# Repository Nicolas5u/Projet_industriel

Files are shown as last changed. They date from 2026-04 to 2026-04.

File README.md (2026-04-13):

# English readme below the French readme
# Projet industriel
Ce projet est un projet étudiant en lien avec l'entreprise Sony CSL

# Montage outil Seringue

L’outil Seringue a pour objectif de rendre la jubilee capable d'utiliser une seringue automatiquement, rendant notamment capable d'obtenir une quantité constante d’eau dans les puits d’une plaque multi-puits (2.5 +- 0.3 ml). Les problématiques de contamination des liquides ne sont pas prises en compte dans cette solution.

D’un point de vue mécanique nous avons une pièce support qui permet de fixer le moteur à courant continu permettant un effort vertical sur la seringue. La deuxième pièce fixée à la première permet de fixer la partie extérieure de la seringue au support et de fixer le capteur de liquide.

Electronique : nous avons utilisé une raspberry pi connectée à un driver mjkdz pour alimenter et contrôler le moteur à courant continu. Le capteur de liquide est directement connecté à une arduino (utilisé en tant que convertisseur analogique numérique).
Le MJDKZ motor driver module sert principalement à contrôler facilement la vitesse (permet d’augmenter ou diminuer la vitesse du moteur, d’avoir un contrôle souple et précis) et le sens d’un moteur DC (pont en h) à partir d’un microcontrôleur, tout en lui fournissant l’alimentation appropriée (externe à la carte arduino) et en le protégeant (des surtensions, pics de courant, parasites électriques).
Le capteur de niveau de liquide sert principalement à détecter la présence et mesurer la profondeur d'un fluide (jusqu'à 48 mm) à partir d'un microcontrôleur disposant d'une entrée analogique, tout en offrant une lecture continue (grâce à un circuit d'amplification par transistor générant une tension proportionnelle à l'immersion) utilisable pour concevoir facilement des systèmes d'alarme ou de surveillance de niveau.

Il est nécessaire d’acheter le moteur :  
https://www.amazon.fr/Actuator-electronic-controller-EKFBQBGW-5V-50mm-15N/dp/B0D9RP563V?th=1&psc=1  

Il est nécessaire d’acheter un driver :  
https://fr.aliexpress.com/item/1005008699170894.html  

Il est nécessaire d’acheter un convertisseur analogique numérique (en remplacement de la carte arduino) :  
https://fr.aliexpress.com/item/1005007112138921.html  

Il est nécessaire d’imprimer :  
1 : Piece_support_outil_seringue.stl  
2 : Piece_capteur_outil_seringue.stl  
3 : Piece_maintien_seringue.stl  
4 : Piece_moteur_outil_seringue.stl  

Les pièces sont également visibles sur Printables :
https://www.printables.com/model/1675196-piece_support_outil_seringue



# Test sur la seringue

L’objectif est ici de mesurer la différence de quantité d'eau déversée par l'outil seringue. Pour ce faire nous avons positionné la seringue à une hauteur qui restera constante durant toute la durée de l'expérience. Il nous a alors suffit d’utiliser la fonction remplissage de puits qui actionne le moteur jusqu’à ce que le sensor envoie une valeur supérieure à celle prédéfinie.  


Il est important de noter que certains biais ont été remarqués comme une goutte d’eau qui serait restée au niveau de la seringue.  




# Code
Première utilisation de l’outil seringue 

-> allumer raspi + machine Jubilee  
-> connection au wifi : CSLToi  
-> dans la barre de recherche d’un navigateur : http://jubilee.local/ ou  http://10.0.9.6/  
-> Faire le homing pour vérifier que tout va bien (touche du tableau de bord “ Tout au Origines”)  

Cloner le repo https://github.com/leosabatie-eng/science-jubilee.git    
 
Installer conda (plus propre avec le lien qu’avec une commande du terminal) :  
https://docs.conda.io/projects/conda/en/stable/user-guide/install/windows.html  

-> se positionner dans le fichier science_jubilee  
-> conda create -n jubilee26 python=3.9  
-> conda activate jubilee26  

-> conda install conda-forge::jupyterlab  
-> jupyter lab  

Utilisation de l’outil seringue

Une fois les étapes de première connexion réalisées, l’utilisation de l’outil seringue se fait par la compilation du serveur qui envoie les données du capteur et reçoit l’instruction pour le moteur qui actionne la seringue.  

Dans un terminal:  
-> ssh jubilee@[adresse IP]
il est demandé le mot de passe : [mdp]  
-> python serveur_pi.py

Dans un terminal (au niveau de science jubilee):  
-> conda activate jubilee26  
-> jupyter lab  

Aller sur l’interface sur internet  
Se déplacer dans le répertoire science-jubilee/src/science_jubilee/a_netbookTest/test_ser.ipynb  

Modification d’un fichier de l’espace mémoire de la raspberry  

Dans le cas de modification du fichier il est conseillé d’utiliser vscode avec son extension   
remote - ssh la commande et le mots de passe pour se connecter reste identique. Il est alors facile d’ouvrir le dossier home/jubilee qui contient tous les codes qui sont dans l’espace mémoire de la raspberry et de les modifier.  

Utilisation du code test_ser.ipynb  

Seules deux fonctions sont réellement nécessaires pour la manipulation de l’outil seringue  
-> tool1.remplir_seringue(temps_secondes=10.0)  
-> tool1.avancer_jusqu_au_seuil(seuil=1, timeout_sec=5)  
la première permet de remplir la seringue pendant le temps indiqué en paramètre (il y est fixé un temps de 4 secondes de vidage de la seringue au début de la fonction)  
la seconde permet de vider la seringue jusqu’à un certain niveau de seuil (valeur en volt facilement réglable avec le fichier “moniteur_capteur.py” il faut bien sur avoir lancé le serveur et être sur le wifi CSL toi)  

Erreur dans l’utilisation du code test_ser.ipynb  

En cas de difficulté dans les liens (les imports sont introuvables) faire : pip install -e dans un terminal au niveau de science jubilee  

# Industrial_project
This project is a student project in collaboration with the company Sony CSL

# Syringe tool assembly

The Syringe tool aims to make the Jubilee capable of using a syringe automatically, notably enabling it to obtain a constant amount of water in the wells of a multi-well plate. Liquid contamination issues are not taken into account in this solution.

From a mechanical point of view, we have a support part that allows the motor to be mounted, providing vertical force on the syringe. The second part, attached to the first one, allows the outer part of the syringe to be fixed to the support and to mount the liquid sensor.

Electronics: we used a Raspberry Pi connected to an mjkdz driver to power and control the motor. The liquid sensor is directly connected to an Arduino (used as an analog-to-digital converter).
The MJDKZ motor driver module is mainly used to easily control the speed (allows increasing or decreasing the motor speed, providing smooth and precise control) and the direction of a DC motor (H-bridge) from a microcontroller, while providing it with the appropriate power supply (external to the Arduino) and protecting it (from overvoltages, current spikes, and electrical noise).
The liquid level sensor is mainly used to detect the presence and measure the depth of a fluid (up to 48 mm) from a microcontroller with an analog input, while offering continuous reading (thanks to a transistor amplification circuit generating a voltage proportional to the immersion) usable to easily design alarm or level monitoring systems.

It is necessary to buy the motor: 
[https://www.amazon.fr/Actuator-electronic-controller-EKFBQBGW-5V-50mm-15N/dp/B0D9RP563V?th=1&psc=1](https://www.amazon.fr/Actuator-electronic-controller-EKFBQBGW-5V-50mm-15N/dp/B0D9RP563V?th=1&psc=1)

It is necessary to print:  
1 : Piece_support_outil_seringue.stl  
2 : Piece_capteur_outil_seringue.stl  
3 : Piece_maintien_seringue.stl  
4 : Piece_moteur_outil_seringue.stl  

The parts are also visible on Printables:
[https://www.printables.com/model/1675196-piece_support_outil_seringue](https://www.printables.com/model/1675196-piece_support_outil_seringue)



# Syringe test

The objective here is to measure the difference in the amount of water dispensed by the syringe tool. To do this, we positioned the syringe at a height that will remain constant throughout the duration of the experiment. We then simply used the well-filling function, which activates the motor until the sensor sends a value higher than the predefined one.  


It is important to note that some biases were noticed, such as a drop of water that might have stayed on the syringe tip.  




# Code
First use of the syringe tool  

-> turn on raspi + Jubilee machine  
-> connect to wifi: CSLToi  
-> in a browser's search bar: [http://jubilee.local/](http://jubilee.local/) or [http://10.0.9.6/](http://10.0.9.6/)  
-> Home the machine to check that everything is fine (dashboard button "Home All" / "Tout aux origines")  

Clone the repo https://github.com/leosabatie-eng/science-jubilee.git  
 
Install conda (cleaner with the link than with a terminal command):  
[https://docs.conda.io/projects/conda/en/stable/user-guide/install/windows.html](https://docs.conda.io/projects/conda/en/stable/user-guide/install/windows.html)  

-> navigate into the sciencejubilee folder  
-> conda create -n jubilee26 python=3.9  
-> conda activate jubilee26  

-> conda install conda-forge::jupyterlab  
-> jupyter lab

Using the syringe tool  

Once the initial connection steps are completed, the syringe tool is used by running the server which sends the sensor data and receives the instruction for the motor that actuates the syringe.

In a terminal:
-> ssh jubilee@[IP]
the password is requested: [..]  
-> python serveur_pi.py  

In a terminal (at the science jubilee level):  
-> conda activate jubilee26  
-> jupyter lab  

Go to the web interface  
Navigate to the directory science-jubilee/src/science_jubilee/a_netbookTest/test_ser.ipynb  

Modifying a file in the Raspberry Pi's memory space  

If modifying the file, it is recommended to use vscode with its remote - ssh extension. The command and password to connect remain the same. It is then easy to open the home/jubilee folder which contains all the codes that are in the Raspberry Pi's memory space and modify them.  

Using the test_ser.ipynb code  

Only two functions are actually for manipulating the syringe tool  
-> tool1.remplir_seringue(temps_secondes=10.0)  
-> tool1.avancer_jusqu_au_seuil(seuil=1, timeout_sec=5)  
the first one allows filling the syringe for the time indicated in the parameter (a 4-second syringe emptying time is set at the beginning of the function)  
the second one allows emptying the syringe up to a certain threshold level (voltage value easily adjustable with the "python moniteur_capteur.py" file, you must of course have launched the server and be on the CSLToi wifi)  

Error when using the test_ser.ipynb code  

In case of difficulty with the links (imports cannot be found) run: pip install -e in a terminal at the science jubilee level

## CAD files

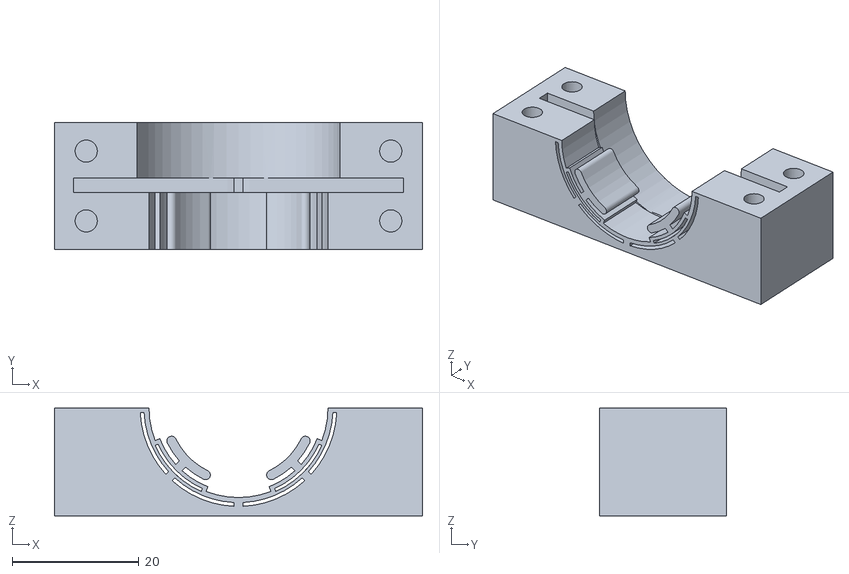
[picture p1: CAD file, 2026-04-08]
Piece_maintien_seringue.STL
58.0 x 20.0 x 17.0

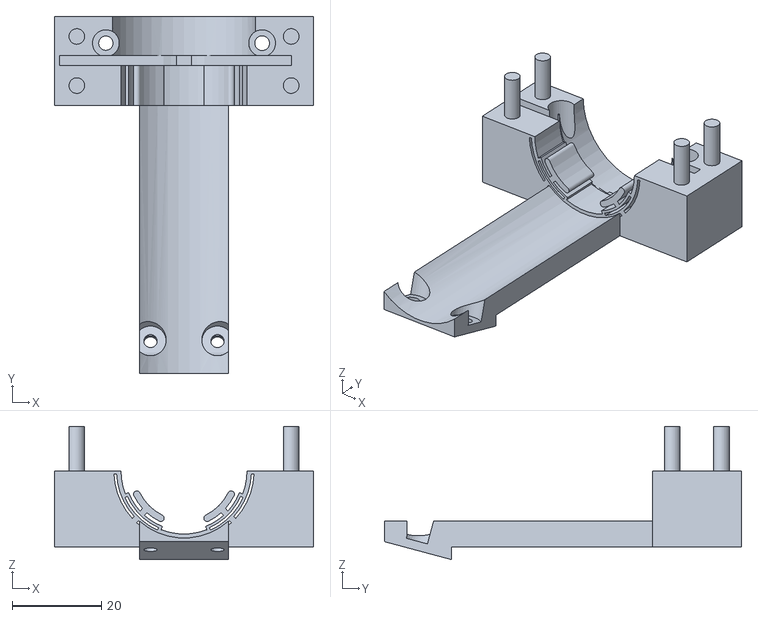
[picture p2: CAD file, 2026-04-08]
Piece_capteur_outil_seringue.STL
58.0 x 80.0 x 29.8

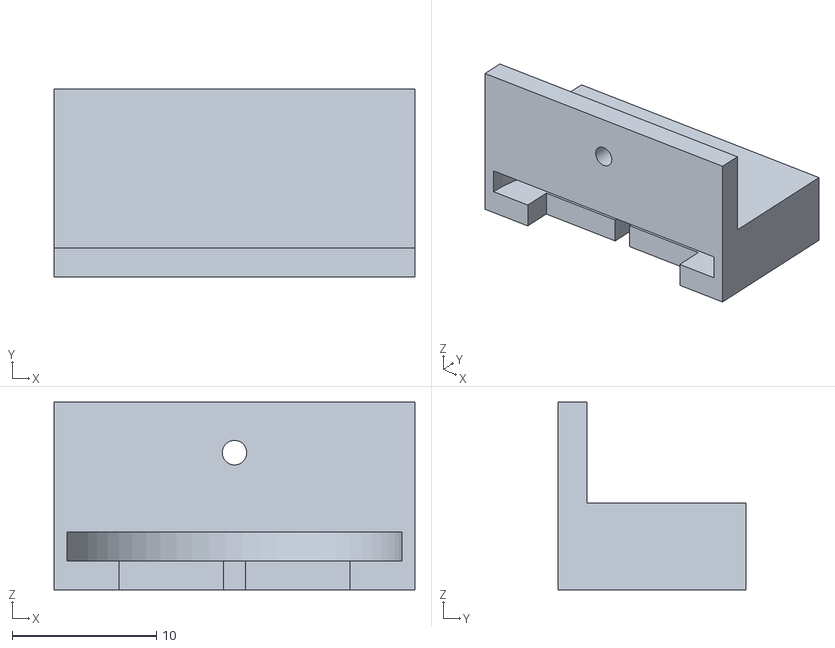
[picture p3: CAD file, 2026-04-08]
Piece_moteur_outil_seringue.STL
25.0 x 13.0 x 13.0

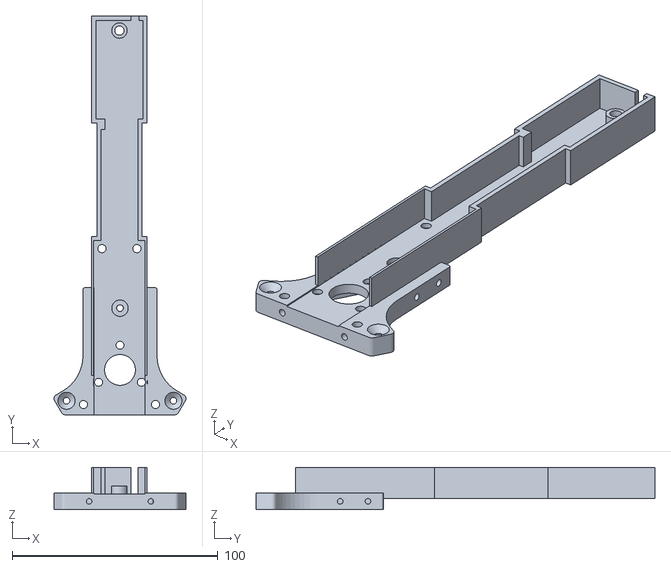
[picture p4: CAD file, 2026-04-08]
Piece_support_outil_seringue.STL
64.2 x 193.8 x 20.5

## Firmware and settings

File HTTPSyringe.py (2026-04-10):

import json
import logging
import os
import time
from itertools import dropwhile, takewhile
from typing import Iterator, List, Tuple, Union

import numpy as np
import requests

from science_jubilee.labware.Labware import Labware, Location, Well
from science_jubilee.tools.Tool import (
    Tool,
    ToolConfigurationError,
    ToolStateError,
    requires_active_tool,
)


class HTTPSyringe(Tool):
    def __init__(self, index, name, url, ip_raspberry="10.0.9.55"):
        """
        HTTP Syringe est un client pur : parle à Jubilee (url) et à notre serveur Pi.
        """
        self.name = name
        self.index = index
        self.url = url
        # ⚠ Port 5001 pour éviter le conflit avec OctoPrint
        self.url_materiel = f"http://{ip_raspberry}:5001"  

        # --- Initialisation HTTP standard de Jubilee ---
        config_r = requests.post(url + "/get_config", json={"name": name})
        config = config_r.json()
        super().__init__(index, **config, url=url)

        # Vérifie le serveur Pi
        self._init_gpio()

        # Status initial
        status_r = requests.post(url + "/get_status", json={"name": name})
        status = status_r.json()
        self.syringe_loaded = status.get("syringe_loaded", False)
        self.remaining_volume = status.get("remaining_volume", 0.0)

    def _init_gpio(self):
        """
        Initialise la connexion réseau avec le serveur matériel du Raspberry Pi.
        
        Cette fonction effectue un "ping" (requête GET) vers le Raspberry Pi pour 
        vérifier s'il est allumé et prêt à recevoir des commandes. Elle met à jour 
        l'attribut `self.gpio_disponible` en conséquence.

        Auteur : Nicolas Durand (Projet étudiant - Sony CSL)
        """
        if getattr(self, "gpio_disponible", False):
            return

        try:
            requests.get(f"{self.url_materiel}/capteur", timeout=2)
            self.gpio_disponible = True
            print(f"[{self.name}] Connecté au serveur matériel du Raspberry Pi.")
        except requests.exceptions.RequestException:
            self.gpio_disponible = False
            print(f"[{self.name}] ERREUR : Impossible de joindre le Pi sur {self.url_materiel}.")

    def lire_capteur(self):
        """
        Interroge le Raspberry Pi pour obtenir la valeur immédiate du capteur de liquide.
        
        Idéal pour le monitoring en direct ou pour tester le capteur sans activer le moteur.

        Returns:
            tuple: (tension en Volts, valeur_brute de 0 à 1023). 
                   Retourne (None, None) en cas d'échec de connexion.

        Auteur : Nicolas Durand (Projet étudiant - Sony CSL)
        """
        self._init_gpio()
        if not getattr(self, "gpio_disponible", False):
            return None, None
            
        try:
            req = requests.get(f"{self.url_materiel}/capteur", timeout=2)
            reponse = req.json()
            tension = reponse.get("tension", 0.0)
            brute = reponse.get("brute", 0)
            return tension, brute
        except Exception:
            return None, None

    @requires_active_tool
    def avancer_jusqu_au_seuil(self, seuil: float = 1.0, timeout_sec: int = 5):
        """
        Descend l'outil vers le réservoir jusqu'à la détection du liquide.
        
        Active le moteur en marche avant et interroge en boucle le capteur via le Pi.
        Dès que la tension lue est supérieure ou égale au seuil, le moteur s'arrête.
        Intègre une sécurité (timeout) pour éviter le crash physique de l'outil si 
        le capteur est défaillant ou le réservoir vide.

        Args:
            seuil (float): La tension cible (en Volts) confirmant la présence de liquide.
            timeout_sec (int): Temps maximum (en secondes) avant l'arrêt d'urgence.

        Raises:
            ToolStateError: Si le serveur Raspberry Pi est injoignable avant le mouvement.

        Auteur : Nicolas Durand (Projet étudiant - Sony CSL)
        """
        self._init_gpio()
        if not getattr(self, "gpio_disponible", False):
            raise ToolStateError("Le serveur Pi n'est pas joignable.")

        print(f"[{self.name}] Ordre au Pi : Moteur forward (Attente seuil >= {seuil}V)")
        requests.post(f"{self.url_materiel}/moteur", json={"action": "forward", "speed": 1.0})
        
        start_time = time.time()
        try:
            while True:
                try:
                    req = requests.get(f"{self.url_materiel}/capteur", timeout=1)
                    tension_actuelle = req.json().get("tension", 0.0)
                except Exception:
                    tension_actuelle = 0.0 

                if tension_actuelle >= seuil:
                    print(f"[{self.name}] Seuil atteint ({tension_actuelle:.2f}V).")
                    break
                    
                if (time.time() - start_time) > timeout_sec:
                    print(f"[{self.name}] Timeout atteint ({timeout_sec}s).")
                    break
                    
                time.sleep(0.1)
                
        finally:
            # Bloc "finally" garantissant l'arrêt du moteur même en cas de crash (Ctrl+C)
            requests.post(f"{self.url_materiel}/moteur", json={"action": "stop"})
            print(f"[{self.name}] Moteur arrêté.")

    @requires_active_tool
    def remplir_seringue(self, temps_secondes: float):
        """
        Exécute une séquence de purge et de remplissage automatisée de la seringue.
        
        1. Marche avant (4s) : Vide l'air ou le liquide résiduel dans le réservoir source.
        2. Marche arrière (variable) : Aspire le nouveau liquide.

        Args:
            temps_secondes (float): Durée d'activation du moteur en marche arrière pour l'aspiration.

        Auteur : Nicolas Durand (Projet étudiant - Sony CSL)
        """
        self._init_gpio()
        if not getattr(self, "gpio_disponible", False):
            raise ToolStateError("Le serveur Pi n'est pas joignable.")

        temps_vide = 4.0
        print(f"[{self.name}] Vidage en cours pour {temps_vide} sec...")
        requests.post(f"{self.url_materiel}/moteur", json={"action": "forward", "speed": 1.0})
        time.sleep(temps_vide)

        print(f"[{self.name}] Remplissage en cours pour {temps_secondes} sec...")
        requests.post(f"{self.url_materiel}/moteur", json={"action": "backward", "speed": 1.0})
        time.sleep(temps_secondes)

        requests.post(f"{self.url_materiel}/moteur", json={"action": "stop"})
        print(f"[{self.name}] Remplissage terminé.")

        if hasattr(self, 'capacity'):
            self.remaining_volume = self.capacity

    def cleanup_gpio(self):
        """
        Sécurité logicielle de fin d'utilisation.
        S'assure que le moteur ne reste pas bloqué en position de marche si le script 
        principal s'arrête brutalement. À appeler à la toute fin des expériences.
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

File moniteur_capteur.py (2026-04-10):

"""
Moniteur du Capteur de Liquide (Outil Client)
=============================================
Ce script est un outil d'affichage en temps réel (CLI) pour surveiller 
la valeur du capteur de liquide de la Jubilee. Il interroge régulièrement 
le serveur Flask du Raspberry Pi et génère une jauge visuelle dans le terminal.

Auteur : Nicolas Durand (Projet étudiant - Sony CSL)
"""

import requests
import time
import os

# CONFIGURATION RÉSEAU

IP_RASPBERRY = "10.0.9.55"
PORT = "5001"
URL_CAPTEUR = f"http://{IP_RASPBERRY}:{PORT}/capteur"


def effacer_ecran():
    """
    Efface le contenu de la console (terminal) pour simuler une interface dynamique.
    """
    os.system('cls' if os.name == 'nt' else 'clear')


print(" Démarrage du moniteur de capteur...")
time.sleep(1)

try:
    # Boucle principale (tourne à l'infini jusqu'à ce qu'on fasse Ctrl+C)
    while True:
        try:
            # 1. On interroge l'API du Raspberry Pi pour avoir l'état du capteur
            # Les proxies sont désactivés pour forcer la requête sur le réseau local
            req = requests.get(URL_CAPTEUR, timeout=3, proxies={"http": None, "https": None})
            reponse = req.json()
            
            # 2. Extraction des données reçues (0.0 par défaut si la clé n'existe pas)
            tension = reponse.get("tension", 0.0)
            brute = reponse.get("brute", 0)
            erreur = reponse.get("erreur", "")

            # 3. Création d'une jauge visuelle (0 à 5V = 20 blocs)
            # On s'assure que la tension ne dépasse pas 5.0 ou ne soit pas sous 0.0
            tension_affichee = max(0, min(tension, 5.0)) 
            # Calcul du nombre de blocs pleins (règle de trois)
            nb_blocs = int((tension_affichee / 5.0) * 20)
            # Création de la chaîne de caractères (ex: ████████------------)
            barre = "█" * nb_blocs + "-" * (20 - nb_blocs)

            # 4. Affichage de l'interface dans le terminal
            effacer_ecran()
            print("================================")
            print(" MONITEUR DU CAPTEUR DE LIQUIDE")
            print("================================\n")
            print(f" Connecté à : {URL_CAPTEUR}\n")
            
            # Affichage de l'erreur si l'Arduino a eu un problème de lecture
            if erreur:
                print(f" Avertissement du Pi : {erreur}")
            else:
                print(f" Tension lue : {tension:.2f} V")
                print(f" Valeur brute: {brute} / 1023\n")
                print(f"Jauge visuelle : [{barre}]")
            
            print("\n(Appuyez sur Ctrl+C pour quitter)")

        except requests.exceptions.RequestException:
            # Gestion du cas où le Raspberry Pi est éteint, déconnecté du Wi-Fi, 
            # ou si le serveur Flask n'est pas lancé.
            effacer_ecran()
            print("================================")
            print(" MONITEUR DU CAPTEUR DE LIQUIDE")
            print("================================\n")
            print(f" ERREUR : Impossible de joindre le Pi sur {IP_RASPBERRY}")
            print("-> Vérifiez que 'serveur_pi.py' tourne bien sur le Raspberry.")
            print("-> Vérifiez que vous êtes sur le même Wi-Fi.")
            print("\n(Nouvelle tentative dans 2 secondes...)")
            
            # On attend un peu plus longtemps si le réseau est coupé pour ne pas spammer
            time.sleep(1.8) 

        # On attend 0.2s avant de rafraîchir l'écran (environ 5 images par seconde)
        time.sleep(0.2)

except KeyboardInterrupt:
    # Se déclenche proprement si l'utilisateur fait un Ctrl+C dans le terminal
    effacer_ecran()
    print("⏹️ Moniteur fermé. Bonne continuation ! (Nicolas Durand - Sony CSL)")

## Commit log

2026-04-08 Update README.md lien printable
2026-04-08 Update README.md photo dans la partie eng
2026-04-10 Update README.md repo de leo
2026-04-13 Update README.md ajout des liens d'achat
